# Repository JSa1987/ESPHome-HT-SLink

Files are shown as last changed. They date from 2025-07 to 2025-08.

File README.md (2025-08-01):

# ESPHome Home Theater Controller with Sony S-Link support

This is an ESPHome controller I made to fully control my home theater setup from Home Assistant. This controller includes the following input/outputs that suit my needs, but it can be easily modified for different setups.
- Sony S-Link Input/Output - Used to control a Sony CDP-CX225 CD Player
- IR Input - Used to detect ON/OFF and Volume commands from a Roku remote
- IR Output - Used to control a Yamaha RX-V2700 receiver and a daisy chained IR blaster
- ON/OFF Output (5v) - Used to control a power conditioner (completly turn off the power to the whole setup)
- 12v ON/OFF Input - Used to detect the ON/OFF status of the Yamaha RX-V2700 receiver
- 5v ON/OFF Input- Used to detect the ON/OFF status of the TV (connected to a USB port of the TV)

## Sony S-Link
An Arduino Pro Mini is used as interface for the Sony S-Link Bus. The Arduino is interfaced with the ESP8622 via a serial connection.
The Arduino sketch (in the `Arduino Sketch` folder) is entirely based on the great work from [robho](https://github.com/robho/sony_slink). The only change is that the modified code allows the option of communicating over serial using raw Hex bytes. This is achieved by defining the 'HexOutput' option at the beginning of the code (if this is not defined the code behaves as the original code). 

I'm successfully using this setup to control and read information from a Sony CDP-CX225 CD Player. The ESPHome yaml file with the configuration for this device is available in the `ESPHome` folder. 

## Hardware
To physically connect the ESP8266, the Arduino, the Sony device to be controlled via the S-Link bus and the other devices (e.g. IR blaster, Power Conditioner etc.) some additional components are needed. See schematic below.
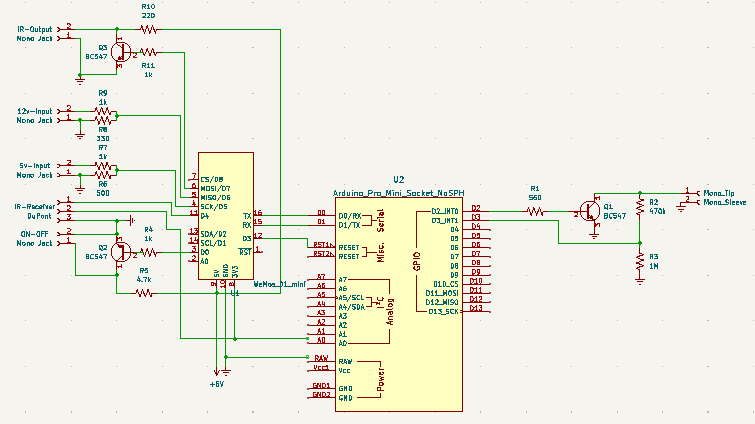
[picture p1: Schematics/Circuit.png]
circuit


The S-Link bus operates at a 5v logic level, while the ESP8266 operates at a 3.3v logic level. There are Arduino boards that operate either at 3.3v or at 5v, therefore the circuit will depend on the type of Arduino board used. The schematics above uses an the 3.3v version of the Arduino Pro Mini, therefore the Arduino can be connected directly to the ESP8266 but R2 and R3 are needed as voltage divider on the S-Link bus line. If an Arduino that operates at 5v logic level is used instead (e.g. Arduino Nano) then R2 and R3 won't be needed but a logic level shiftier will instead be needed between the Arduino and the ESP8266.

For the Sony S-Link interface a 3.5 mm mono plug shall be used to connect the circuit to the S-Link/Control A1 port of the Sony device.
A 3.5 mm mono plug would be used also to connect to most IR blasters and IR input ports on receivers, the signal goes on the mono plug tip and the ground on the sleeve.

## Home Assistant interface
### Entities
The ESPHome device exposes the following entities:
- `switch.living_room_av_power_conditioner_switch` Switch to control the ON/OFF Output (5v)
- `binary_sensor.living_room_av_yamaha_receiver_status` Binary Sensor for the 12v ON/OFF Input 
- `binary_sensor.living_room_av_tv_status` Binary Sensor for the 5v ON/OFF Input 
- `button.living_room_av_reboot` Button to reboot the ESP8266
- `button.living_room_av_arduino_reset` Button to reboot the Arduino

The ESPHome device also exposes the following services that can called from Home Assistant:
- `esphome.living_room_av_remote_nec` Used to send an IR commands using the NEC protocol. Two parameters are to be provided when calling the service `address` and `command`.
- `esphome.living_room_av_remote_pioneer` Used to send an IR commands using the Pioneer protocol. One parameter is to be provided when calling the service `rc_code_1`.
- `esphome.living_room_av_cdp09` Used to send commands on the the S-Link bus. One parameter is to be provided when calling the service `command`. See the links at the bottom of the page for the known S-Link commands.

For each device on the S-Link bus specific sensors will then need to be defined in the ESPHome yaml configuration file. This is done using the ESPHome [UARTX custom component](https://github.com/eigger/espcomponents) to process the data received from the Arduino over UART and expose it to Home Assistant as entities.
The ESPHome configuration file in the 'ESPHome' folder includes the configuration for a CDP-CX225 CD Player, but can be easily adjusted for other Sony devices (see the links at the bottom of the page for the expected responses from S-Link devices).

### Setup for Sony CDP-CX225

The following template sensors are to be defined in the Home Assistant `configuration.yaml`:
- cdp_album => This will reflect the title of the CD loaded.
- cdp_artist => This will reflect the artist of the track playing
- cdp_track_title => This will reflect the title of the track playing
- cdp_bar => This will reflect the current position in the track been played as percentage of the track duration. 
```
template:
  - sensor:
      - name: "CD Album"
        unique_id: cdp_album
        state: |
          {% from "cdp_cd_list.jinja" import cdp_cd_list %}
          {{ cdp_cd_list.cd[(states("sensor.living_room_av_cd_playing")|int)-1].Album}}
  - sensor:
      - name: "CD Artist"
        unique_id: cdp_artist
        state: |
          {% from "cdp_cd_list.jinja" import cdp_cd_list %}
          {{ cdp_cd_list.cd[(states("sensor.living_room_av_cd_playing")|int)-1].Artist}}
  - sensor:
      - name: "CD Track Title"
        unique_id: cdp_track_title
        state: |
          {% from "cdp_cd_list.jinja" import cdp_cd_list %}
          {{ cdp_cd_list.cd[(states("sensor.living_room_av_cd_playing")|int)-1].Tracks[(states("sensor.living_room_av_playing_track")|int)-1]}}
  - number:
      - name: "CDP Track bar"
        unique_id: cdp_bar
        state: '{{ ((states("sensor.living_room_av_track_positon_s")|int) / (states("sensor.living_room_av_track_length_s")|int) * 100)|int}}'
        step: 1
        set_value: 
          - service: script.av_cdp_jumptime
            data:
              jump_to: "{{ value }}"
```

In addtion, the following Helpers need to be created in Home Assistant:
- `input_select.cdp_cd_list` This is used to provide a drop down list to pick the CD to be played
- `input_select.cdp_cd_tracks` This is used to provide a drop down list to pick the track to be played

The details of the CDs loaded in the CDP-CX225 are defined in the `cdp_cd_list.jinja` file. For each CD this file details the Artist, the Album Name, the Number of Tracks and the Title of each track. An example of this file is provided in the `Home Assistant` folder. This file needs to be placed in the Home Assistant `custom_templates` sub-folder.

The following Scripts and Automatons are provided in the `Home Assistant` folder:
- `AV_CDP_Refresh_Album-Track.yaml` Automation triggered each time the track played changes to update `input_select.cdp_cd_list` and `input_select.cdp_cd_tracks` to reflect the CD and track currently been played.
- `AV_CDP_Power_Toggle.yaml` Script to toggle ON and OFF the power to the CDP-CX225
- `AV_CDP_JumpTime.yaml` Script to jump to a specific time of the current track
- `AV_CDP_Play_Disc-Track.yaml` Script to play a specific CD and Track
- `AV_CDP_Update_CD_List.yaml` Script to load an updated content from the `cdp_cd_list.jinja` file (this needs to be run each time Home Assistant is re-started)

### Card for Sony CDP-CX225
To control the CDP-CX225 I created a "custom card" based on [Conditional Media Player Card from CollotsSpot](https://github.com/CollotsSpot/Conditional-Media-Player).

Card Screenshot 2

This card requires the following customs cards to be installed via HACS:
- [Button Card](https://github.com/custom-cards/button-card)
- [My Cards Bundle](https://github.com/AnthonMS/my-cards)
- [Decluttering Card](https://github.com/custom-cards/decluttering-card)

The content of `decluttering_template.yaml` from the Home Assistant folder needs to be pasted at top of your dashboard yaml file (Edit Dashboard > Three dot menu > raw configuration editor). A manual card then needs to be added to the dashboard with the following content (entities and colors can be edited as needed).

```
      - type: custom:decluttering-card
        template: cd_player
        variables:
          - service_call: esphome.living_room_av_cdp09
          - power_toggle: script.av_cdp_power_toggle
          - play_disk_track: script.av_cdp_play_disc_track
          - cd_status: sensor.living_room_av_cd_status
          - cd_playing: sensor.living_room_av_cd_playing
          - track_playing: sensor.living_room_av_playing_track
          - cd_power_status: binary_sensor.living_room_av_cd_power_status
          - cd_track_position: sensor.living_room_av_track_positon_s
          - cd_track_length: sensor.living_room_av_track_length_s
          - cd_list: input_select.cdp_cd_list
          - track_list: input_select.cdp_cd_tracks
          - primary-color: '#6F8081'
          - secondary-color: rgba(96,114,116,0.6)
          - button-background-color: rgba(96,114,116,0.2)
```

----
## Additional resources
The S-Link_CDP-CX225.xlxs file in the 'SLink Supported Commands' folder lists the commands I have found work with the CDP-CX225.

## S-Link reference documents:
* [S-Link Parallel Device for Linux](http://web.archive.org/web/20070705130320/http://www.undeadscientist.com/slink/)
* [How SONY's S-LINK/CTRL-A(II) protocol works](http://web.archive.org/web/20180831072659/http://boehmel.de/slink.htm)

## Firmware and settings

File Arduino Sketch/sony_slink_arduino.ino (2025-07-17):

//#define DEBUG_PULSES

// HexOutput defines if the serial input/ouput are Hex bytes (e.g. to communicate with ESP8266) or a Hex string (e.g.to communicate with the Arduino IDE serail monitor).
// Leave the line uncommented to communicate using Hex bytes, or comment it to communicate using Hex strings.
//#define HexOutput

const byte OUTPUT_PIN = 11;
const byte INPUT_PIN = 3; //Only pin 2 or 3 can be used, interput is needed
const byte PULSE_BUFFER_SIZE = 200;

volatile unsigned long timeLowTransition = 0;
volatile byte bufferReadPosition = 0;
volatile byte bufferWritePosition = 0;
volatile byte pulseBuffer[PULSE_BUFFER_SIZE];

#ifdef DEBUG_PULSES
String pulseLengths;
#endif

#ifdef HexOutput
const byte numByteBuffer = 16; //UART RX Buffer size
const char endMarker = 0x0A; //UART command delimiter (RX)
#endif

void setup()
{
  pinMode(OUTPUT_PIN, OUTPUT);
  digitalWrite(OUTPUT_PIN, LOW);
  pinMode(INPUT_PIN, INPUT);
  attachInterrupt(digitalPinToInterrupt(INPUT_PIN), busChange, CHANGE);
  delay(5000);
  Serial.begin(9600);
}

// This interrupt handler receives data from a remote slink device
void busChange()
{
  static unsigned long timeOfPreviousInterrupt = 0;
  unsigned long timeNow = micros();

  if (timeNow - timeOfPreviousInterrupt < 100) {
    return;
  }
  timeOfPreviousInterrupt = timeNow;

 int busState = digitalRead(INPUT_PIN);
  if (busState == LOW) {
    timeLowTransition = timeNow;
    return;
  }

  // Bus is high. The time that the bus has been low determines what
  // has happened. Let's store this information for analysis outside
  // of the interrupt handler.
  int timeLow = timeNow - timeLowTransition;

  if ((bufferWritePosition + 1) % PULSE_BUFFER_SIZE == bufferReadPosition) {
#if !defined(HexOutput)
    Serial.println(F("Pulse buffer overflow when receiving data"));
#endif
    return;
  }

  // Divide by 10 to make the pulse length fit in 8 bits
  pulseBuffer[bufferWritePosition] = min(255, timeLow / 10);
  bufferWritePosition = (bufferWritePosition + 1) % PULSE_BUFFER_SIZE;
}

void processSlinkInput()
{
  static byte currentByte = 0;
  static byte currentBit = 0;
  static bool partialOutput = false;

  while (bufferReadPosition != bufferWritePosition) {
    int timeLow = pulseBuffer[bufferReadPosition] * 10;

    bufferReadPosition = (bufferReadPosition + 1) % PULSE_BUFFER_SIZE;

#ifdef DEBUG_PULSES
    if (timeLow > 2000) {
      pulseLengths = String();
    }
    else {
      pulseLengths += " ";
    }
    pulseLengths += String(timeLow, DEC);
#endif

    if (timeLow > 2000) {
      // 2400 us -> new data sequence               
      if (partialOutput) {
#ifdef HexOutput 
        Serial.write(0x0A);
#else
        if (currentBit != 0) {
          Serial.print(F("!Discarding "));
          Serial.print(currentBit);
          Serial.print(F(" stray bits"));
        }
        Serial.print('\n');
#endif
        partialOutput = false;
      }

      currentBit = 0;
      continue;
    }

    partialOutput = true;
    currentBit += 1;
    if (timeLow > 900) {
      // 1200 us -> bit == 1
      bitSet(currentByte, 8 - currentBit);
    }
    else {
      // 600 us -> bit == 0
      bitClear(currentByte, 8 - currentBit);
    }

    if (currentBit == 8) {

#ifdef HexOutput
      Serial.write(currentByte);
#else
      if (currentByte <= 0xF) {
        Serial.print(0, HEX);
      }
      Serial.print(currentByte, HEX);
#endif
      currentBit = 0;
    }
  }

  if (partialOutput && isBusIdle()) {
#ifdef HexOutput
    Serial.write(0x0A);
#else
    Serial.print('\n');
#endif
    partialOutput = false;
  }
}

bool isBusIdle()
{
  noInterrupts();
  bool isBusIdle = micros() - timeLowTransition > 1200 + 600 + 20000;
  interrupts();
  return isBusIdle;
}

void sendPulseDelimiter()
{
  digitalWrite(OUTPUT_PIN, LOW);
  delayMicroseconds(600);
}

void sendSyncPulse()
{
  digitalWrite(OUTPUT_PIN, HIGH);
  delayMicroseconds(2400);
  sendPulseDelimiter();
}

void sendBit(int bit)
{
  digitalWrite(OUTPUT_PIN, HIGH);
  if (bit) {
    delayMicroseconds(1200);
  }
  else {
    delayMicroseconds(600);
  }
  sendPulseDelimiter();
}

void sendByte(int value)
{
  for (int i = 7; i >= 0; --i) {
    sendBit(bitRead(value, i));
  }
}

void idleAfterCommand()
{
  delayMicroseconds(20000);
}

bool sendCommand(byte command[], int commandLength)
{
  if (!isBusIdle()) {
    return false;
  }

  noInterrupts();
  sendSyncPulse();
  for (int i = 0; i < commandLength; ++i) {
    sendByte(command[i]);
  }

  // Clear interrupt flags because interrupts triggered when we sent
  // the command and the interrupts are queued for processing once
  // interrupts are re-enabled.
  EIFR = bit(INTF0) | bit(INTF1);

  interrupts();
  idleAfterCommand();
  return true;
}

void processSerialInput()
{
#ifdef HexOutput
  static byte ByteBuffer[numByteBuffer];
  static boolean newData = false;
  static int BufferIndex = 0;
  byte ReadByte;
  
  while (Serial.available() > 0 && newData == false) {
      ReadByte = Serial.read();
      if (ReadByte != endMarker) {
        ByteBuffer[BufferIndex] = ReadByte;
        BufferIndex++;
        if (BufferIndex >= numByteBuffer) {
          BufferIndex = numByteBuffer - 1;
        }
      }
      else {
        newData = true;
      }
    }
  if (newData == true) {
    byte commandBytes[BufferIndex];
    for (int i = 0; i <= BufferIndex - 1 ; ++i) {
      commandBytes[i] = ByteBuffer[i];
    }

    if (sendCommand(commandBytes, BufferIndex)) {
    // If sendCommand is successful read setup to read the next command from the Serial
      newData = false;
      BufferIndex = 0;
    }
  }
#else
  static String bytesReceived;

  while (Serial.available()) {
    bytesReceived += char(Serial.read());
  }

  const int eolPos = bytesReceived.indexOf("\n");
  if (eolPos == -1) {
    return;
  }

  const String command = bytesReceived.substring(0, eolPos);
  bytesReceived.remove(0, command.length() + 1);

#ifdef DEBUG_PULSES
  if (command == "pulsedump") {
    Serial.println(pulseLengths);
    return;
  }
#endif

  // A hexadecimal command is expected
  if (command.length() % 2 != 0) {
    Serial.println(F("Uneven length of serial input"));
    return;
  }

  for (int i = 0; i < command.length(); ++i) {
    if (!isHexadecimalDigit(command[i])) {
      Serial.println(F("Non-hexadecimal serial input"));
      return;
    }
  }

  byte commandBytes[command.length() / 2];
  for (int i = 0; i < sizeof(commandBytes); ++i) {
    String hexByte = command.substring(2 * i, 2 * i + 2);
    commandBytes[i] = strtol(hexByte.c_str(), NULL, 16);
  }

  if (!sendCommand(commandBytes, sizeof(commandBytes))) {
    // If send fails, re-queue command
    bytesReceived = command + "\n" + bytesReceived;
  } 
#endif
}

void loop()
{
  processSlinkInput();
  processSerialInput();
}

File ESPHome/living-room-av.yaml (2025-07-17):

esphome:
  name: living-room-av
  friendly_name: living_room_av
  on_boot:
    - priority: -100
      then:
        - button.press: slink_reset

esp8266:
  board: d1_mini
# Available D3, D2, D1

external_components:
  - source: github://eigger/espcomponents/releases/latest
    components: [ uartex ]
    refresh: always

# Enable logging
logger:
  level: DEBUG
  hardware_uart: UART1

# Enable Home Assistant API
api:
#  encryption:
#    key: "q/KeuSTAa5SDevXgaPgo2LJlvAM4O3f1B8UAzG92btM="

  services:
    - service: remote_nec
      variables: 
        address: int
        command: int
      then:
      - remote_transmitter.transmit_nec:
          address: !lambda 'return address;'
          command: !lambda 'return command;'
    - service: remote_pioneer
      variables:
        rc_code_1: int
      then:
      - remote_transmitter.transmit_pioneer:
          rc_code_1: !lambda 'return rc_code_1;'
    - service: cdp09
      variables:
        command: string
      then:
        - logger.log: "Service call received"
        - uart.write:
            id: s_link
            data: !lambda |-
              std::uint8_t i;
              std::string command_str = command;
              std::vector<uint8_t> commandBytes {0x90};
              for (i = 0; i < command_str.length() / 2; ++i) {
                std::string hexByte = command_str.substr(2 * i, 2);
                commandBytes.push_back(strtol(hexByte.c_str(), NULL, 16));
              }
              commandBytes.push_back(0x0A);
              return commandBytes;


ota:
  - platform: esphome
    password: "PWD"

wifi:
  ssid: !secret wifi_ssid
  password: !secret wifi_password
  manual_ip:
    static_ip: xxx.xxx.xxx.xxx
    gateway: yyy.yyy.yyy.yyy
    subnet: zzz.zzz.zzz.zzz

  # Enable fallback hotspot (captive portal) in case wifi connection fails
  ap:
    ssid: "Living-Room-Av Fallback Hotspot"
    password: "PWD"

captive_portal:

output:
  - platform: gpio
    pin:
      number: D3
      inverted: true
    id: arduino_reset

uart:
  tx_pin: GPIO01
  rx_pin: GPIO03
  baud_rate: 9600
  id: s_link
  debug:
    direction: BOTH
    dummy_receiver: false
    after:
      delimiter: [0x0A]

uartex:
  rx_timeout: 100ms
  tx_delay: 50ms
  tx_timeout: 100ms
  tx_retry_cnt: 3
  rx_header: [0x98]
  rx_footer: [0x0A]
  tx_header: [0x90]
  tx_footer: [0x0A]

switch:
  - platform: gpio
    pin: D0
    inverted: True
    id: power_conditioner_switch
    name: "Living Room Power Conditioner Switch"
    icon: "mdi:power-plug"
    restore_mode: RESTORE_DEFAULT_OFF 

binary_sensor:
  - platform: gpio
    pin: D6
    id: yamaha_receiver_status
    name: "Yamaha Receiver Power Status"
    device_class: power
    icon: "mdi:amplifier"
  - platform: gpio
    pin: D5
    id: tv_status
    name: "TV Power Status"
    device_class: power
    icon: "mdi:television"
  - platform: homeassistant
    name: "TV status"
    entity_id: media_player.samsung_6_series_55
    id: living_room_av_tv_status
    icon: "mdi:television"
  - platform: uartex
    id: cd_power
    name: "CD Power Status"
    device_class: power
    icon: "mdi:disc-player"
    state_on:
      offset: 0
      data: [0x2E]
    state_off:
      offset: 0
      data: [0x2F]

sensor:
  - platform: wifi_signal
    id: living_room_av_wifi
    name: "Living Room AV - WiFi Signal"
    update_interval: 60s  
  - platform: uartex
    name: "CD Loaded"
    id: cd_loaded
    icon: "mdi:disc"
    state: [0x58]
    state_number:
      offset: 1
      length: 1
      precision: 0
  - platform: uartex
    name: "CD Playing"
    id: cd_playing
    icon: "mdi:disc"
    state: [0x50]
    state_number:
      offset: 1
      length: 1
      precision: 0
  - platform: uartex
    name: "Playing Track"
    id: track_playing
    icon: "mdi:file-music-outline"
    state: [0x50]
    state_number: !lambda |-
                div_t track_num = div(data[2], 16);
                return track_num.quot * 10 + track_num.rem;
    on_value:           #Trigger verbose mode when playing
      then:
        - if:
            condition:
              lambda: 'return id(cd_status).state == "Playing" || id(cd_status).state == "Paused";'
            then:
              - uart.write: [0x90, 0x25, 0x0A]
  - platform: uartex
    name: "Track Length [s]"
    id: track_len
    icon: "mdi:clock-time-two-outline"
    state: [0x50]
    state_number: !lambda |-
                div_t minutes = div(data[3], 16);
                div_t seconds = div(data[4], 16);
                return seconds.quot * 10 + seconds.rem + (minutes.quot * 10 + minutes.rem) * 60;
  - platform: uartex
    name: "Track Positon [s]"
    id: track_pos
    icon: "mdi:av-timer"
    state: [0x51]
    state_number: !lambda |-
                div_t minutes = div(data[3], 16);
                div_t seconds = div(data[4], 16);
                return seconds.quot * 10 + seconds.rem + (minutes.quot * 10 + minutes.rem) * 60;
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
